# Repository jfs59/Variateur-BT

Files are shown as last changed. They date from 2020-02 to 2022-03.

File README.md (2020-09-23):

# Variateur-BT

  <p align="center">
Addon variateur BT pour Radio Commande.
  
Réalisation d’un variateur double pour bateau et d’un ensemble de 8 voies supplémentaires.
</p> 

<p align="center">
  

</p> 
  </br> </br>
  <p align="center">
  Schéma de principe
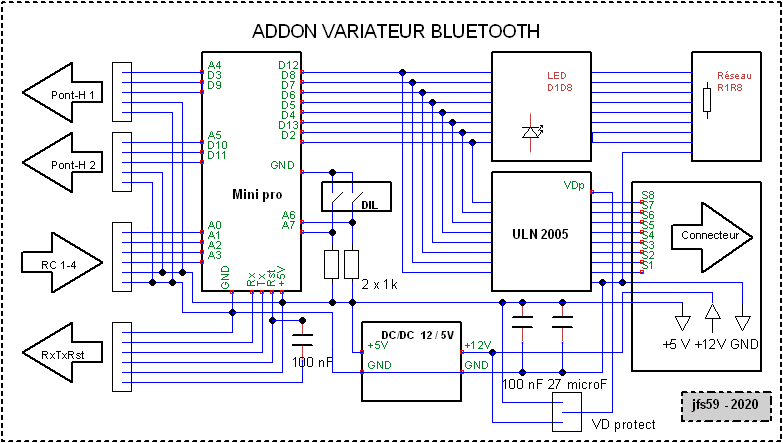
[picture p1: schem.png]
  
</p>

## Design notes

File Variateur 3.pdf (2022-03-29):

### DOUBLE VARIATEUR DE VITESSE POUR BATEAUX

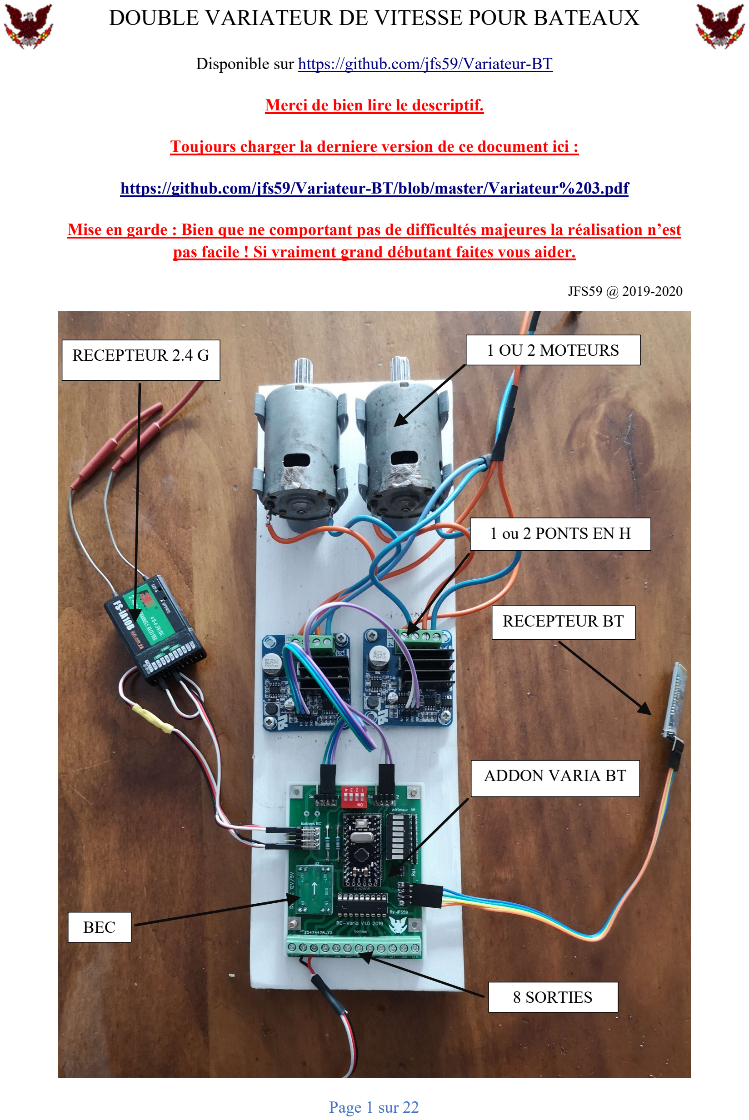
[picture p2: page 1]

Page 1 sur 22

Disponible sur https://github.com/jfs59/Variateur-BT

Merci de bien lire le descriptif.

Toujours charger la derniere version de ce document ici :

https://github.com/jfs59/Variateur-BT/blob/master/Variateur%203.pdf

Mise en garde : Bien que ne comportant pas de difficultés majeures la réalisation n’est pas facile ! Si vraiment grand débutant faites vous aider.

JFS59 @ 2019-2020

### 1 ou 2 PONTS EN H

RECEPTEUR BT

ADDON VARIA BT

RECEPTEUR 2.4 G

BEC

### 8 SORTIES

### 1 OU 2 MOTEURS

Page 2 sur 22

### Table des matières

Page 3 sur 22

Réalisation d’un variateur double et d’un ensemble de 8 voies supplémentaires.

Préambule :

Librement inspiré de : http://bateaux.trucs.free.fr/huit_sorties_auto_v3.html je n’ai gardé pratiquement que l’idée, l’ensemble du code, les schémas ont étés réécris et optimisés tant au niveau du décodage de la mémorisation et des options en fait il reste très peu sinon rien du travail de M Claverie à part l’idée (Il suffit de regarder les extraits de code pour s’en convaincre) qu’il en soit remercié. Certains commentaires sont en Anglais ! Je le déplore mais c’est malheureusement plus concis et souvent plus simple que le Français. La première version était une simple extension sans variateur mais la demande pressante des membres du club on fait que… Cette version bien que non décrite existe toujours et elle est finalisée. (Sauf pour la partie mp3)

Matériel :

Arduino pro mini, afficheur barre de led, réseau de résistance, ULN 2005, Bornes de sorties pour circuit imprimé, convertisseur DC/DC 12V → 5V, IBT-4 (pont en H), Bluetooth JDY-30, Mp3 à définir.

Principe :

L’Arduino décode les signaux RC PPM (4 canaux) et génère les pwm nécessaires à la commande de deux IBT-4 (pont en H) à partir des canaux 1 et 2.

Si fonctionnement sur un seul canal des deux moteurs :

Le canal 2 est affecté au gouvernail et permet suivant le mode de fonctionnement de fonctionner en moteur différentiel.

Le canal 3 est décodé pour activer le canal 4 en sortie ou en demande de bruiteur (module mp3 facultatif)

Le canal 4 est décodé pour commander 8 sorties ULN 2005 selon le principe d’extension de voie. (8 voies sur un canal). En fonction du canal 3 il permet de commander 8 bruits différents, (corne, cloche, diesel)

L’ensemble est configurable par liaison Bluetooth à l’aide d’un programme spécifique développé pour Android. Un mode simulateur est disponible.

Sont configurables : (En plus du mode de fonctionnement)

Limite haute télécommande Canal 1 : 2000 par défaut.

Limite basse télécommande Canal 1 : 1000 par défaut.

Neutre Canal 1 : 1500 par défaut.

Limite haute télécommande Canal 2 : 2000 par défaut.

Limite basse télécommande Canal 1 : 1000 par défaut.

Neutre Canal 2 : 1500 par défaut.

Largeur zone neutre : +/- 50 par défaut.

Pourcentage AV Pourcentage AR Canal 1 : 100% par défaut.

Pourcentage AV Pourcentage AR Canal 2 : 100% par défaut.

Mode de fonctionnement des 8 sorties : Monostables Bistables : 4 monostables, 4 bistables par défaut.

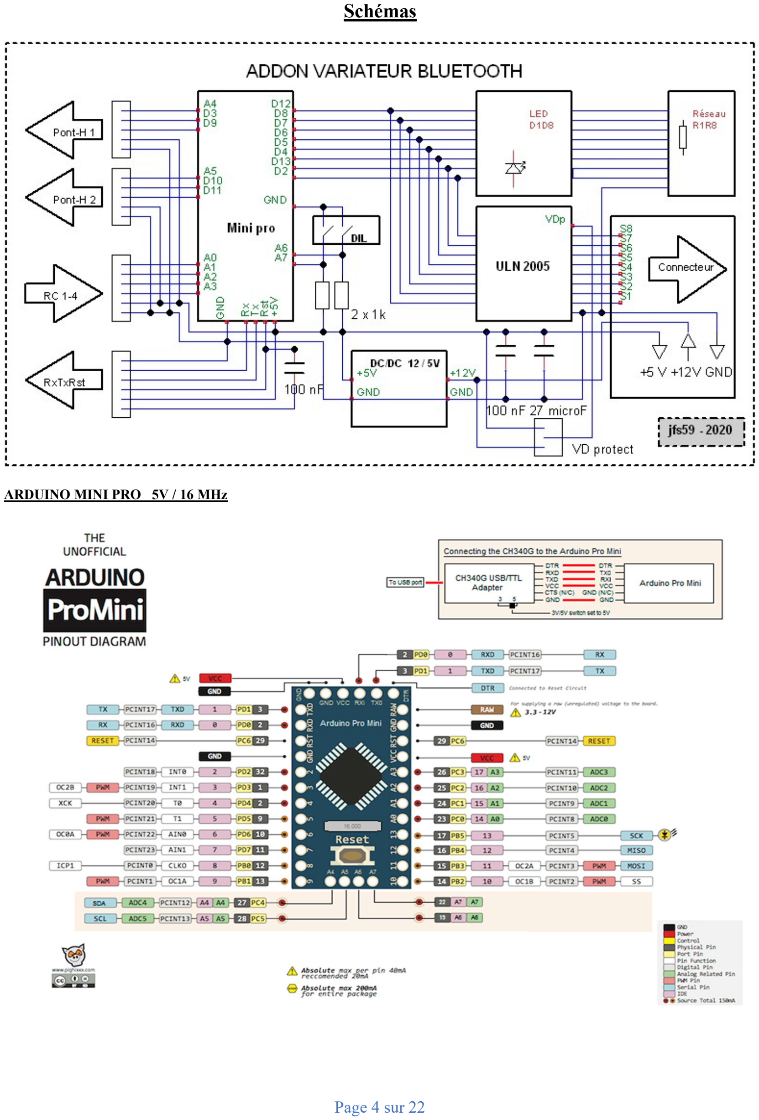
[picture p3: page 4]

Page 4 sur 22

Schémas

ARDUINO MINI PRO 5V / 16 MHz

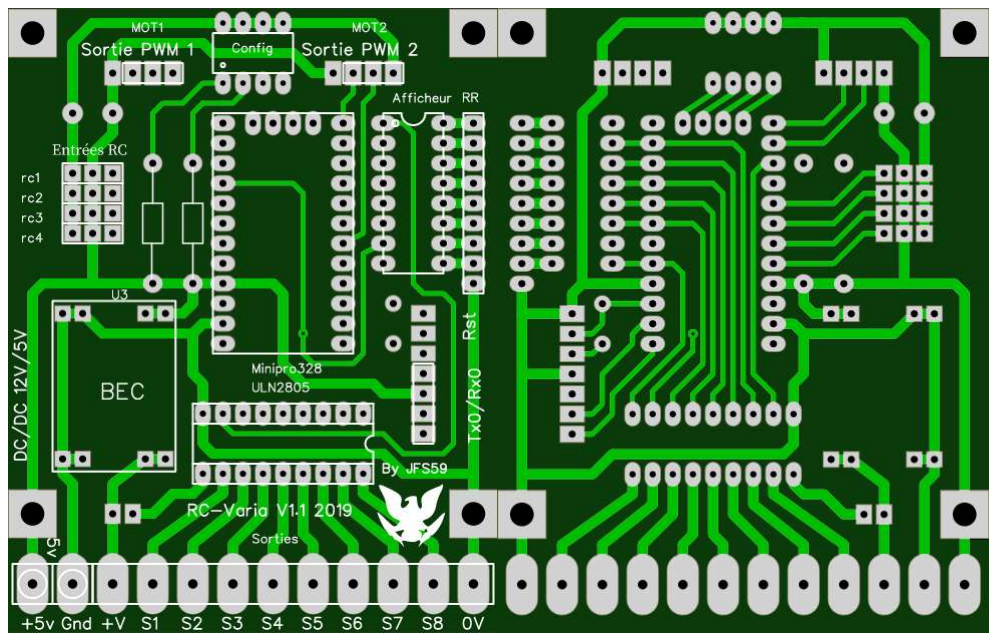
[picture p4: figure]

Page 5 sur 22

Circuit imprimé

Circuit double face, trous métallisés, vernis épargne, et sérigraphie. Dessiné et routé par mes soins. Réalisé par une entreprise.(Le résultat donne un CI professionnel) Le routage et le design sont donnés ci-dessous mais les fichiers Gerber sont et resteront ma propriété. Le circuit imprimé V3 est disponible pour la somme de 5 € couvrant les frais de réalisation et transport. ( Me contacter au club de Raismes. )

Remarque : l’utilisation de A6 et A7 en numérique implique des résistances de tirage au +. A6 et A7 étant purement analogique il faut utiliser une astuce de programmation.

Le bootloader de la carte devra être changé pour empêcher le clignotement au reset de la carte ! sinon il faut faire attention au rôle de la sortie S7 qui va s’allumer au reset !!

Dans la version 3 le circuit imprimé a changé car la programmation Bluetooth a pris le dessus sur la configuration par DIL (cf. schéma de principe) des sorties supplémentaires pour les ponts en H sont disponibles. Elles permettront d’utiliser des ponts en H autre que l’IBT4.

L’entrée commune de protection par diodes de l’ULN peut être reliée soit au 12 V soit au 5 V (version 3) soit rester non utilisée (cas de tensions différentes sur les sorties)

### Bien vérifier à la commande car de nombreuses variantes incompatibles !!

ATTENTION : il faut un Pro Mini Atmega328P 5V/16M avec le même brochage du CI de [ A4 à A7 ]

Attention il existe des modules avec une broche Gnd en plus ils ne sont pas directement compatibles.

Pour ces modèles il est toujours possible d’adapter en passant des fils sous la carte.

Attention : Les Atmega168 ne sont pas compatibles ! Méfiez vous des revendeurs qui disent le contraire.

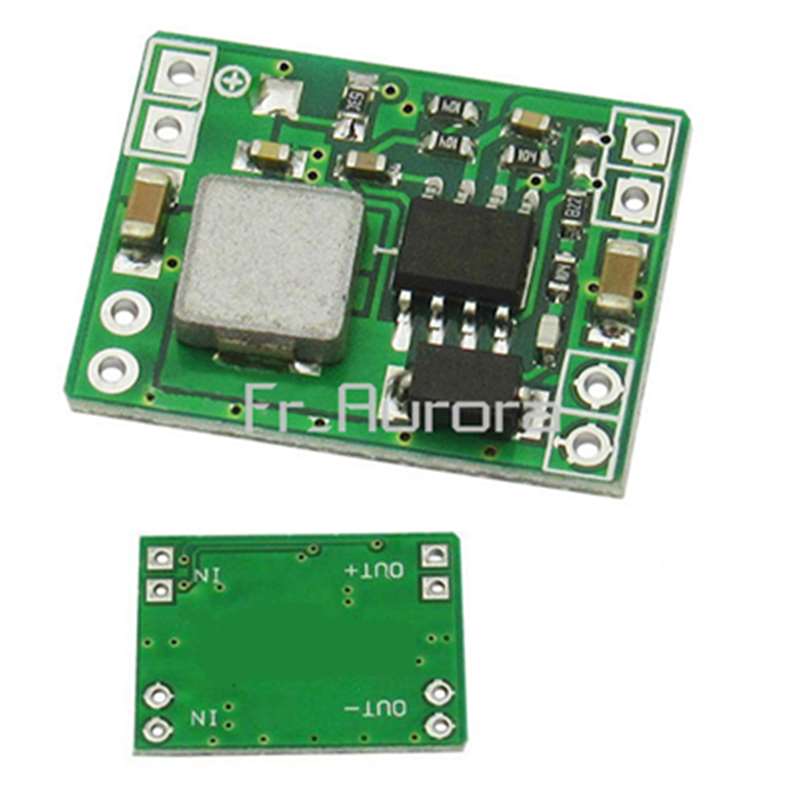
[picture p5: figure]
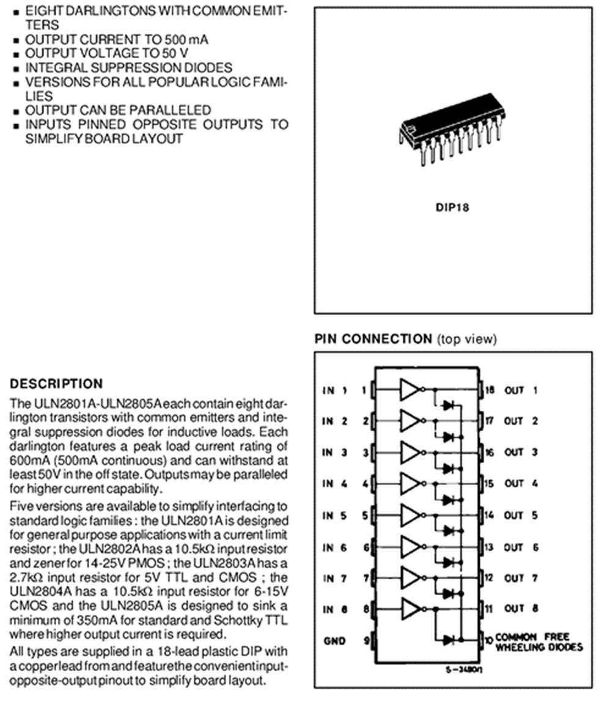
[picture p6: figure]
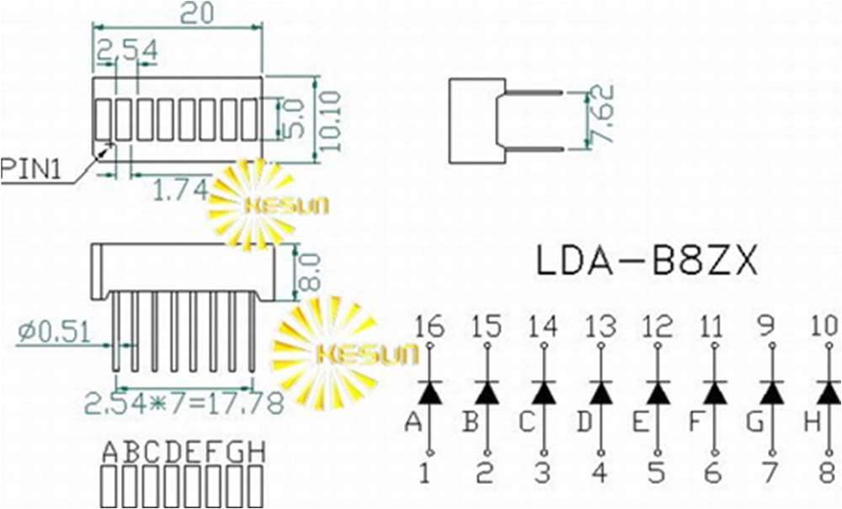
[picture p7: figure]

Page 6 sur 22

Composants et sous-ensembles.

Convertisseur DC/DC 12 V/ 5 V

Utilisé pour alimenter l’Arduino et les diodes de visualisation. Une sortie 5 V est prévue pour alimenter un montage externe.

Sur la première version montage du convertisseur composant en dessous !

Version 3 le convertisseur est positionné composants au-dessus.

ULN 2005 interface de puissance

Permet de relayer les sorties Arduino afin de disposer d’un courant de sortie plus important et d’une tension différente, peuvent se mettre en // pour augmenter le courant de sortie il suffit de les souder patte pour patte l’un au-dessus de l’autre,

Diode anti retour de protection communes à toutes les sorties. (Attention si vous n’êtes pas sûr de l’utilisation faites-vous aider)

Les sorties OUT sont mises à la masse quand un niveau haut (1) est présent à l’entrée correspondante.

Bargraphe led

Visualise l’état des canaux et donc des sorties de puissance. Les cathodes sont reliées à la masse à travers un réseau des 8 résistances dont le point commun est à la masse.

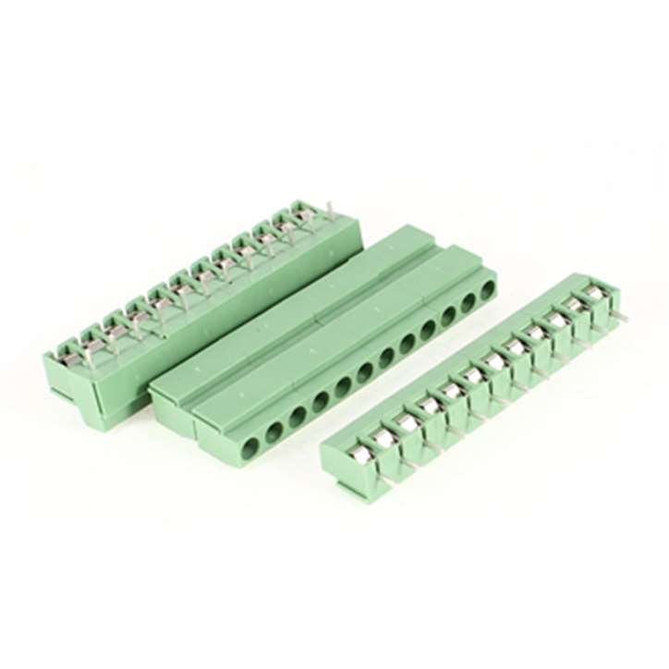
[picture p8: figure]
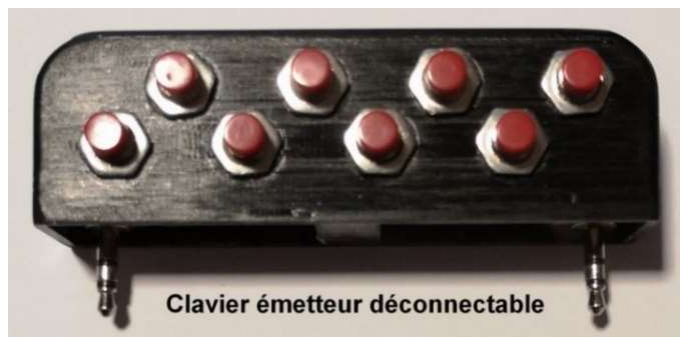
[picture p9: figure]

Page 7 sur 22

Interrupteur DIL

Permettent de choisir le mode de fonctionnement de 0 à 15. Depuis la version Bluetooth le mode est configurable par le programme Android.

Le DIP ne fait plus que 2 rangées sur la version 3.

Off Off : mode Bluetooth. On Off : 1 moteur.

Off On : 2 moteurs 1 commande. On On : 2 moteurs 2 commandes.

Réseau de 8 résistances

Choisir la valeur entre 470 Ohm et 1 K Ohm,

Borniers a vis clipsables,

Par 2 ou 3 il en faut 12 : 2 X6 ou 3 X4

Un fichier imprimante 3D est disponible sur le

Github

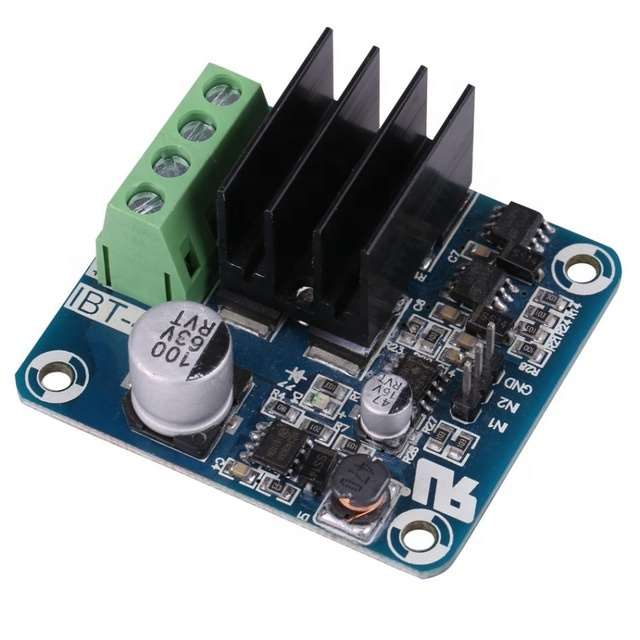
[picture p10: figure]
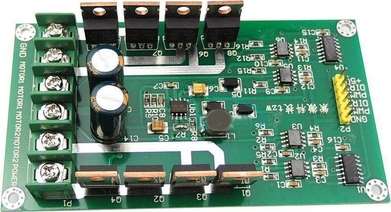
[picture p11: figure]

Page 8 sur 22

IBT4 Pont en H

Caractéristiques :
- Module driver Pont H à courant élevé (50A) MOSFET
- Isolation galvanique du signal PWM.
- Rotation avant et arrière du moteur, deux entrées PWM au maximum 200kHz
- Alimentation 3.3V à 15V.

Le module possède sa propre alimentation donc seulement 3 fils à brancher la masse et les deux entrées PWM.

Double Pont en H

Caractéristiques :
- Module driver Pont H (10 A ou 15 A) MOSFET

Courant nominal : 10A

Courant de crête : 30A

Moteur avant : DIR = 1 PWM = PWM

Inversion du moteur : DIR = 0 PWM = PWM

Frein de stationnement : DIR = X PWM = 0 (X est un état arbitraire)

(Pas compatible encore en développement)

Monster Pont en H

Caractéristiques :
- Module driver Pont H à courant élevé (30A) MOSFET

(Pas compatible encore en développement)

Page 9 sur 22

IBT2 Pont en H

Caractéristiques :
- Module driver Pont H à courant élevé (43A) MOSFET

(Pas compatible encore en développement)

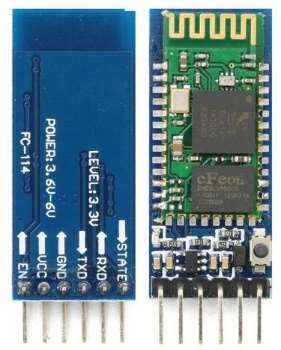
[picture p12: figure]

Module Bluetooth HC 05 / JDY-30

Il permet la configuration du variateur (mode de fonctionnement) et des differentes sorties (monostable, bistable) il permet aussi un mode simulation des sorties et des voies du variateur. (Pas utile lors du fonctionnement normal)

Module FTDI / USB

Il permet la programmation du variateur (Pas utile lors du fonctionnement si vous n’avez pas besoin de changer de fichier hex)

Page 10 sur 22

Chronologie de câblage :

Câblage de la version Bluetooth.

Souder les deux résistances cms 1K et vérifier en testant sur le circuit. (Consulter un tuto de soudage cms) Souder la platine alimentation BEC.
Souder une ligne de bornier (possibilité de souder : +V, gnd, +5v uniquement)
Brancher une tension >6 V sur Gnd, +V et vérifier la présence du + 5 V.
Souder le connecteur Rx/Tx Bluetooth et le condensateur c3 de 100 nf. (Pour permettre le flash de la carte Arduino il est aussi possible de flasher à la volée par le connecteur « ftdi »)
Souder les pattes extrêmes du réseau et vérifier le sens et les valeurs. (Souder le reste des pattes)
Souder le support d’afficheur. Placer l’afficheur et vérifier chaque segment en injectant +5 v sur les pastilles correspondantes au niveau de la carte Arduino.
Souder la plaque Arduino MiniPro. (Eventuellement le bootloader noled aura été chargé mais il peut l’être après) Il est peut-être possible d’utiliser une carte non standard (avec gnd) en tordant les pattes A4 A5 A6 A7 (sans garantie)
Charger un sketch (programme) dans l’Arduino.
Mettre sous tension entre Gnd et +V (tension > 6V). Le programme démarre est on doit observer à chaque reset un défilement « bargraphe » sur l’afficheur.
Souder le support ULN.
Placer un ULN et vérifier le bon fonctionnement de chaque sortie (S1 a S8). (Terminer les soudures borniers si nécessaire) Souder l’interrupteur DIL éventuellement sur support.
Souder les connecteurs de sortie PWM. Souder les différents connecteurs. Les condensateurs de découplage sont facultatifs. (Procédure incomplète)

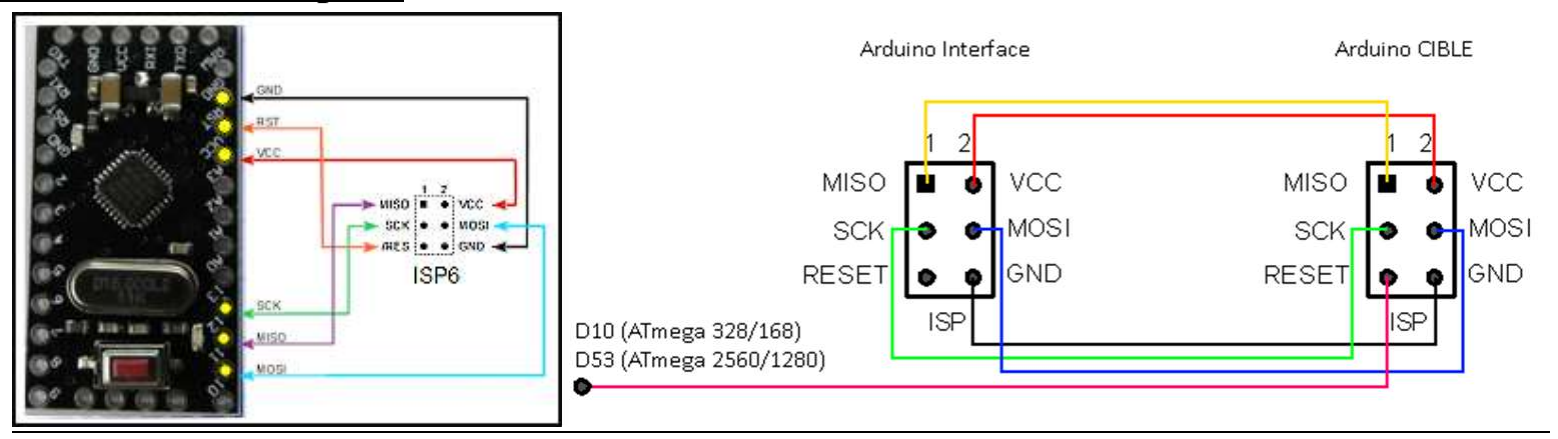
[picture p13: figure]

Page 11 sur 22

Compilation et Flash du Bootloader

Repérage des connecteurs de la mini pro :

Sur le circuit imprimé vous pouvez utiliser les broches support de l’afficheur.
Se référer à la procédure de flash soit avec un ISP soit avec un Arduino câblé en ISP et le programme (Arduino as ISP). Le bootloader zéros LED est disponible sur le GitHub.
Il faut évidemment placer le bootloader noled dans le dossier Arduino et éditer le Board.txt ! https://github.com/jfs59/Variateur-BT/blob/master/mod.ATmegaBOOT_168_atmega328.hex
Ce bootloader no LED a été compile par mes soins et fonctionne avec la mini pro sans problème. Il permet de supprimer le clignotement lors du boot du variateur. (Il n’est pas indispensable si l’activation de la sortie au démarrage ne pose pas de problème sur la maquette)
Compiler un bootloader : (Pour rappel ou besoin différent)

charger et installer GnuWin32

copier : ATmegaBOOT_168.c et Makefile
dans le dossier bin de gnuwin32
(pour aller dans le dossier en ligne de commande : cd \"program files (x86)\GnuWin32\bin" )

dans le makefile : modifier (modification du nombre de clignotement au boot)

atmega328: CFLAGS += '-DMAX_TIME_COUNT=F_CPU>>4' '-DNUM_LED_FLASHES=1' -DBAUD_RATE=57600

en mettant zéro à la place du 1

atmega328: CFLAGS += '-DMAX_TIME_COUNT=F_CPU>>4' '-DNUM_LED_FLASHES=0' -DBAUD_RATE=57600

Lancer un : ./make atmega328 (ne pas oublier ./)

PS C:\program files (x86)\GnuWin32\bin> ./make atmega328
avr-gcc -g -Wall -Os -mmcu=atmega328p -DF_CPU=16000000L '-DMAX_TIME_COUNT=F_CPU>>4' '-DNUM_LED_FLASHES=0' -DBAUD_RATE=57600 -c -o ATmegaBOOT_168.o ATmegaBOOT_168.c
avr-gcc -g -Wall -Os -mmcu=atmega328p -DF_CPU=16000000L '-DMAX_TIME_COUNT=F_CPU>>4' '-DNUM_LED_FLASHES=0' -DBAUD_RATE=57600 -Wl,--section-start=.text=0x7800 -o ATmegaBOOT_168_atmega328.elf ATmegaBOOT_168.o
avr-objcopy -j .text -j .data -O ihex ATmegaBOOT_168_atmega328.elf ATmegaBOOT_168_atmega328.hex
rm ATmegaBOOT_168_atmega328.elf ATmegaBOOT_168.o
PS C:\program files (x86)\GnuWin32\bin>

Renommer le fichier obtenu en mod.ATmegaBOOT_168_atmega328.hex
puis le transférer dans le dossier C:\Program Files (x86)\Arduino\hardware\arduino\avr\bootloaders\atmega

Editer le boards.txt et changer :
pro.menu.cpu.16MHzatmega328.bootloader.file=atmega/mod.ATmegaBOOT_168_atmega328.hex
dans la section pro mini
enfin lancer l'ide arduino, et avec un nano et le programme arduinoisp faire un flash arduino as isp du bootloader lancer 2 fois si le premier ne passe pas ! Puis recharger le sketch.

Page 12 sur 22

Pour flasher le .hex vous pouvez utiliser Xloader en USB ou une autre méthode que vous connaissez. Xloader

A rechercher sur internet ou directement sur le GitHub https://github.com/jfs59/Variateur-BT/blob/master/Outils/XLoader.zip
Choisir le port com (pas forcément le 4) et le fichier Variateur.ino.eightanaloginputs.hex choisir Duemilanove/Nano(ATmega328) appuyer sur upload. La procédure fonctionne je l’ai essayée. (Il est impossible de flasher le bootloader par cette méthode)

Gestion des paramètres en Bluetooth sur ANDROID
Varia config 1.0:
Varia Config 1.0 (et les futures évolutions) permet de gérer les paramètres du variateur a l’aide d’un téléphone ou d’une tablette ANDROID. (Il n’y aura pas d’autres développement que sur ANDROID)
Développé par mes soins à partir de http://ai2.appinventor.mit.edu/
Le programme a beaucoup évolué (et évoluera encore) en fonctions des options ajoutées et des besoins.
Il est disponible ici : https://github.com/jfs59/Variateur-BT/blob/master/Variateur.apk

Ce n’est pas la dernière version et elle n’assure donc pas tout le fonctionnement et toutes les simulations.
Le programme sera mis à jour en fonctions des versions stables qui seront développées ainsi que le sketch Arduino. Il est préférable qu’ils soient de la même période l’un n’allant pas sans l’autre.
Sont en développement :
- Gestion des sons mp3.
- Support des différents ponts en H.
- Vitesses différentielles des moteurs en fonction du gouvernail.
- Résolution de bug de communication Bluetooth.

Commande Bluetooth actuelles :
const char CmdCfg_Str[] PROGMEM = "CmdCfg"; const char CmdEnr_Str[] PROGMEM = "CmdEnr"; const char CmdSim_Str[] PROGMEM = "CmdSim"; const char DemCfg_Str[] PROGMEM = "DemCfg";
const char DemVer_Str[] PROGMEM = "DemVer";
const char DemCon_Str[] PROGMEM = "DemCon";

Ces commandes peuvent être utilisée sur le moniteur série sans module Bluetooth.

<DemCfg> demande de config le variateur envoie sur la ligne série la config en cours.
<DemVer> demande de version le variateur envoie sur la ligne série le numéro de version du programme.
<DemCon> demande de connexion du module bluetooth.

CmdCfg suivie de la config <CmdCfg|1|11|1500|1000|2000|1500|1000|2000|50|100|100|100|100|0|0|0|0|0|0|0|0|1500|1500|1500|1500|1500|1500|1500|1500> Donne une nouvelle configuration au variateur.
<CmdEnr> demande d’enregistrement. La config courante est enregistrée en EEPROM et le variateur reboot.

CmdSim suivie des valeurs de simulation. Autorise ou interdit la simulation est programme les valeurs de simulation de la ligne courante. (A compléter)

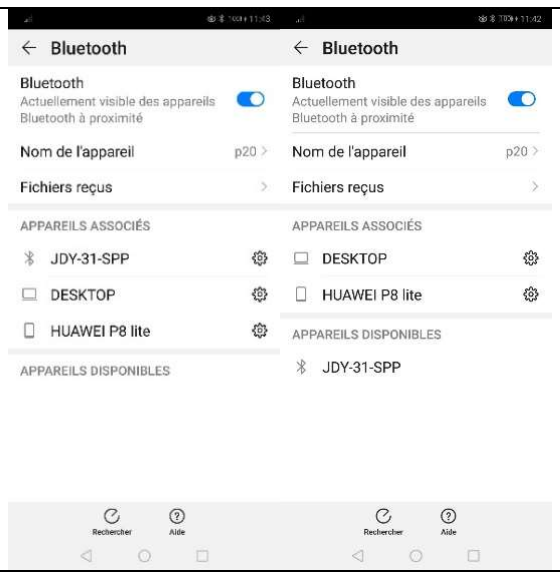
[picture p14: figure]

Page 13 sur 22

Association Bluetooth : Recherche.

Aller dans paramètres Bluetooth rechercher les appareils disponibles et cliquer sur le JDY-31 une fenêtre d’association va apparaitre.

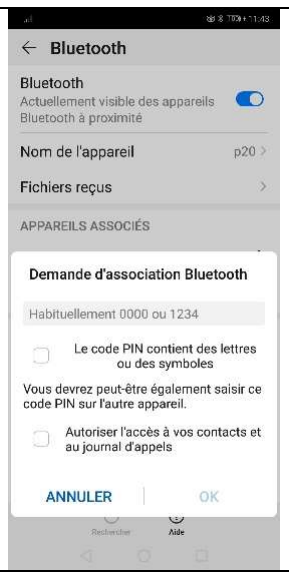
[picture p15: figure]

Association Bluetooth : Code.

Le périphérique Bluetooth demande une confirmation pour s’associer. Le code est 1234. Ne pas cocher les cases supplémentaires.

Association Bluetooth : Association

Une fois associé le périphérique reste dans la liste jusqu’à suppression. Il ne faut donc l’associer normalement qu’une seule fois.

Programme Variateur : Ecran de démarrage

Lancer le programme variateur un splash screen apparait le temps du démarrage.

Page de connexion :

La page connexion apparait. Il faut se connecter avant de continuer sinon vous avez un message disant que le Bluetooth n’est pas connecté.

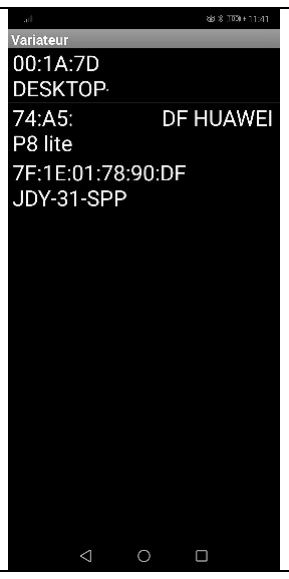
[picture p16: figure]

Choix du périphérique Bluetooth :

Normalement le JDY 31 est dans la liste le choisir. Le téléphone va essayer de se connecter (Cela peut prendre un certain temps)

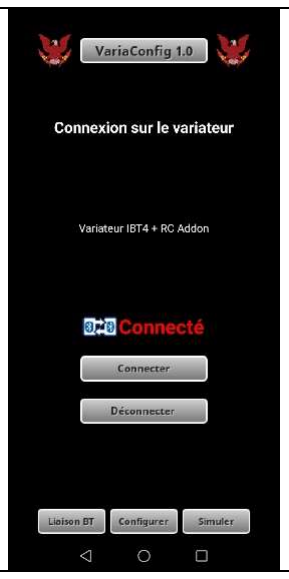
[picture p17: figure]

Connexion :

La page de connexion apparait et un message de version est affiché. Les autres pages sont maintenant disponibles.

Page de mode.

Affiche le mode de fonctionnement du variateur ainsi que le hardware à utiliser.
Permet d’activer le mode mp3.

Page 14 sur 22

Choix du mode :

Permet de choisir un mode de fonctionnement dans les modes disponibles.

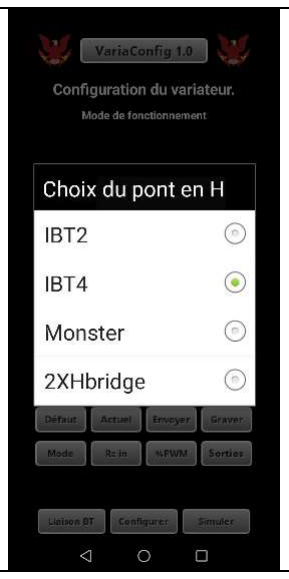
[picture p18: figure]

Choix du matériel :

Permet de choisir le pont en H utilisé par le variateur.
(Seul IBT4 fonctionne pour l’instant)

Paramètres RC :

Permet de choisir les limites du signal RC pour adapter les valeurs.

Paramètres variateur :

Permet de choisir les limites de la tension de sortie en % de batterie d’alimentation du pont en H.

Paramètres Sorties :

Permet de choisir l’action sur les sorties (monostable, bistable) les seuils sont pour l’instant non modifiables.

Valeurs par défaut :

Permet de recharger les valeurs par défaut du variateur dans le programme.

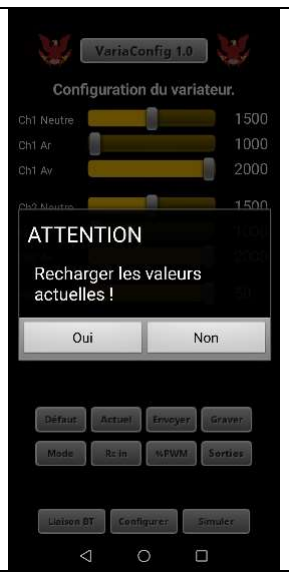
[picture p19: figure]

Valeurs actuelles :

Permet de recharger les valeurs présentent dans le variateur.

Envoyer la configuration :

Permet de charger les valeurs du programme dans le variateur. Elles sont effectives de suite mais ne sont pas sauvegardées. Retour au valeurs sauvegardées au redémarrage.

Page 15 sur 22

Enregistrer la configuration :

Permet de graver les valeurs du programme dans le variateur (EEPROM). Elles deviennent les valeurs de démarrage. Le variateur redémarre automatiquement suite à la sauvegarde.

Simulateur :

Permet de modifier les valeurs en sortie des ponts en H. Et de modifier les valeurs des sorties. Le mode simulateur surpasse les valeurs de la radiocommande.

Page About :

Elle contient les infos sur le programme.

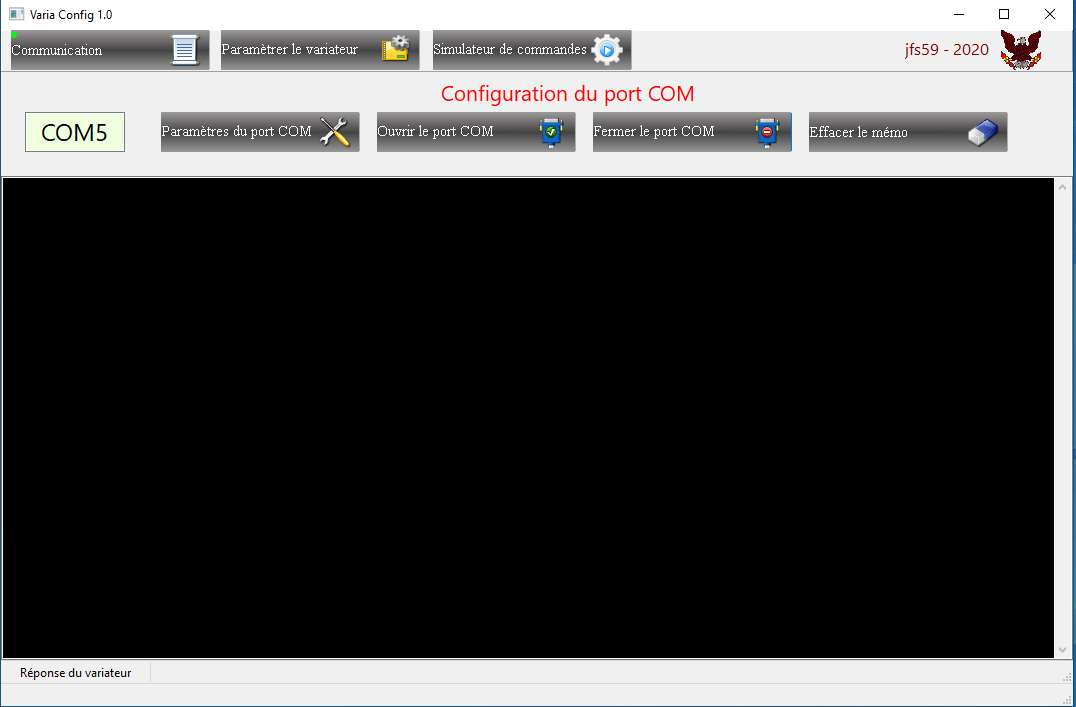
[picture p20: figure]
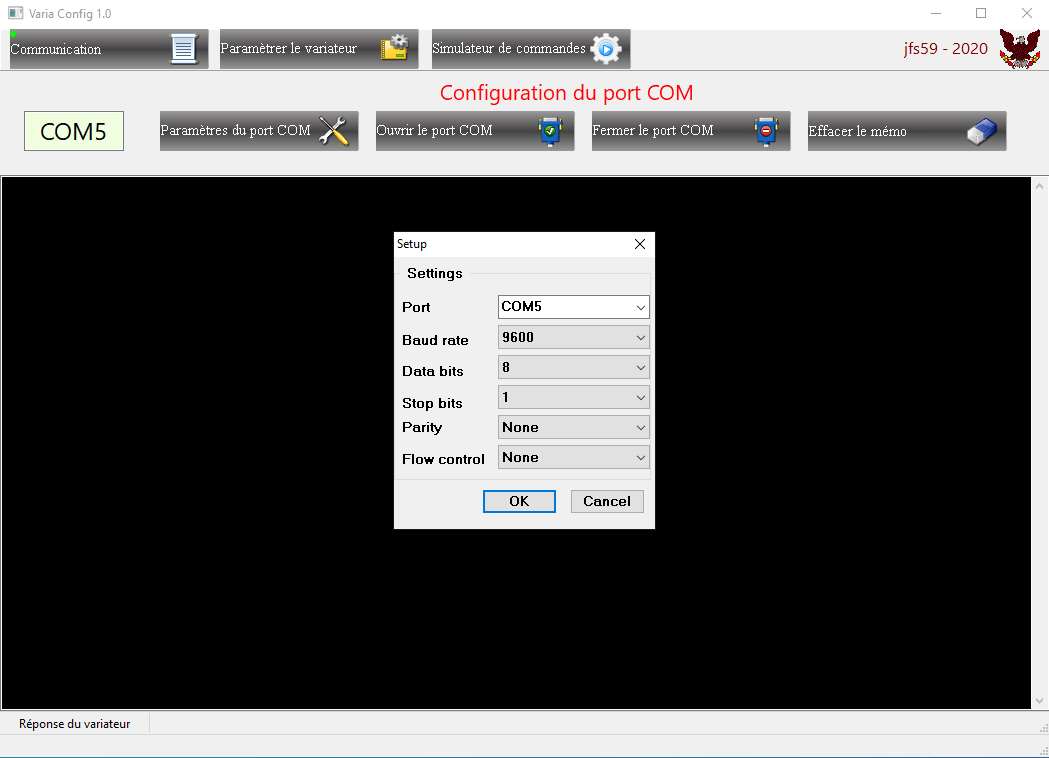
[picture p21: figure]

Page 16 sur 22

Gestion des paramètres sur PC Windows

Le programme de gestion a été écris en Lazarus (Pascal). Il permet de modifier tous les paramètres du variateur ainsi que la simulation.

Page communication :

Choisir le port COM sur lequel est branché le variateur. La configuration par défaut doit être bonne et donc ne pas la modifier.

Ouvrir le port. Une demande est envoyée au variateur qui reboot et réponds par le numéro de version et la configuration actuelle.

La configuration est décodée et les valeurs sont affichées dans le programme.

Un bouton permet de fermer le port et un autre d’effacer le tableau de dialogue.

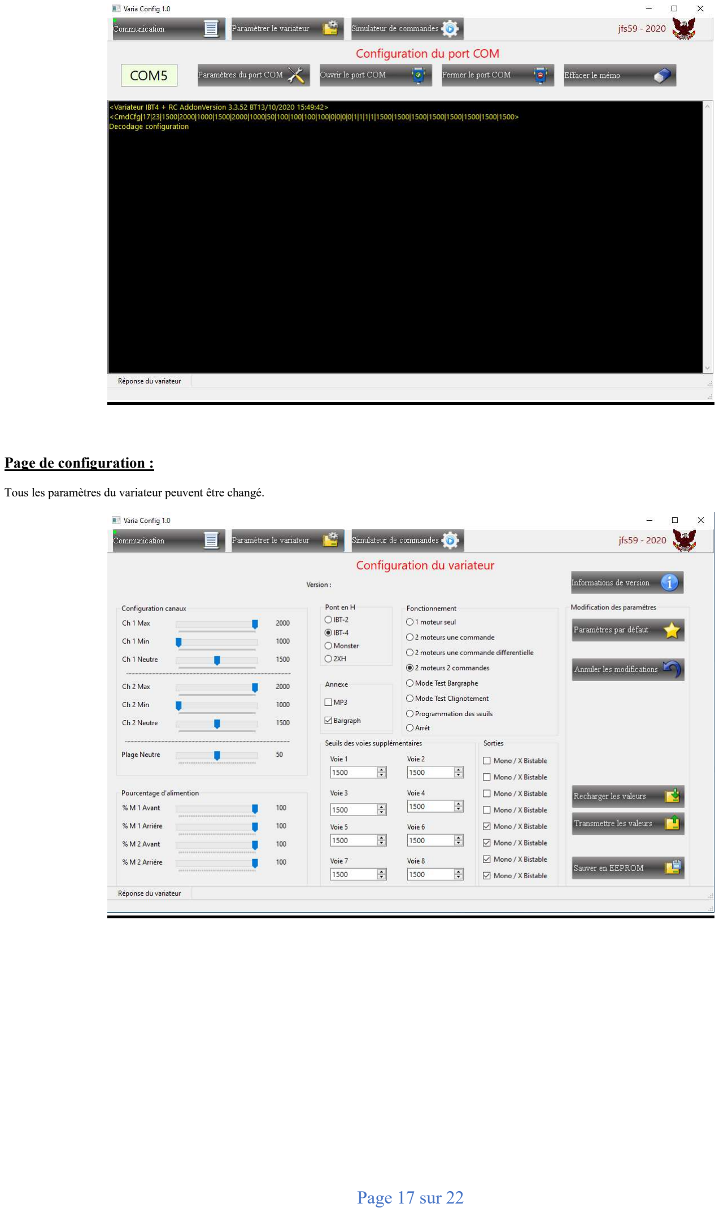
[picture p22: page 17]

Page 17 sur 22

Page de configuration :

Tous les paramètres du variateur peuvent être changé.

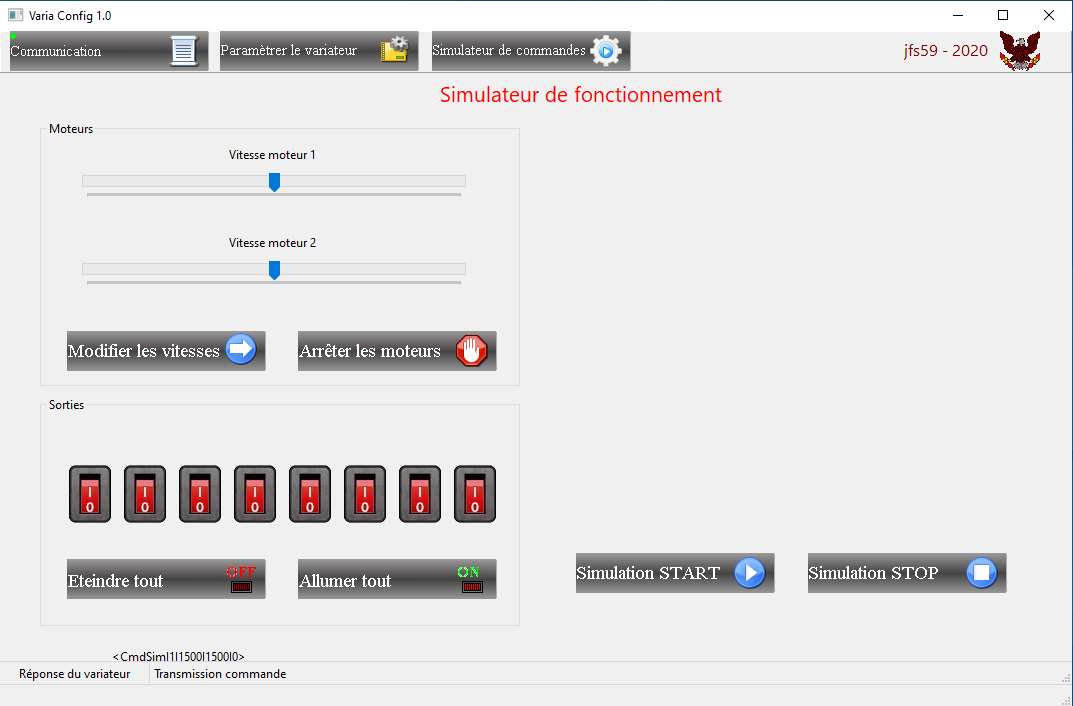
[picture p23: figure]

Page 18 sur 22

Page de simulation :

Page 19 sur 22

Structure et extraits du programme Arduino

Le code complet ne sera pas publié par contre je laisse libre accès au fichier compilé et donc au fichier hexadécimal à programmer avec un USBasp ou un FTDI. (Les initiés comprendront la terminologie) de même je donne libre accès au BOOLOADER modifié. Je peux sous certaines conditions faire pour vous la mise à jour.

Variables de configurations :

struct __attribute__ ((packed)) RC_Config {
byte Structure;
byte ModeFonctionnement;
unsigned int Voie_1_Neutre; unsigned int Voie_1_Arriere; unsigned int Voie_1_Avant; unsigned int Voie_2_Neutre; unsigned int Voie_2_Arriere; unsigned int Voie_2_Avant; byte Plage_Neutre;
byte PourcentAvantV1;
byte PourcentArriereV1;
byte PourcentAvantV2;
byte PourcentArriereV2;
byte ModeSorties[8];
int Seuil_Bouton[8];
unsigned long Flag; // controle d'integrité sauvegarde };

Configuration par défaut :

void DefinirConfigDefaut() { Configuration.Flag = 123456789;
Configuration.STRUCT_VERSION = 1; Configuration.ModeFonctionnement = 23 ; // 2 moteurs 2 commandes séparées. Configuration.Voie_1_Neutre = 1500;
Configuration.Voie_1_Avant = 2000;
Configuration.Voie_1_Arriere = 1000; Configuration.Voie_2_Neutre = 1500; Configuration.Voie_2_Avant = 2000; Configuration.Voie_2_Arriere = 1000; Configuration.Plage_Neutre = 50; Configuration.PourcentAvantV1 = 100; Configuration.PourcentArriereV1 = 100; Configuration.PourcentAvantV2 = 100; Configuration.PourcentArriereV2 = 100;

for ( int n = 0; n < 4; n ++) { Configuration.ModeSorties[n] = 0 ; }

for ( int n = 4; n < 8; n ++) { Configuration.ModeSorties[n] = 1 ;} for ( int n = 0; n < 8; n ++) {Configuration.Seuil_Bouton[n] = 1500 ;} }

Page 20 sur 22

Gestion des entrées RC par interruption :

static byte rcOld; // Prev. states of inputs
volatile unsigned long rcRises[4]; // times of prev. rising edges volatile unsigned long rcTimes[4]; // recent pulse lengths volatile unsigned int rcChange=0; // Change-counter
// Be sure to call setup_rcTiming() from setup()
void setup_rcTiming() {
rcOld = 0;
pinMode(A0, INPUT_PULLUP); // pin 14, A0, PC0, for pin-change interrupt pinMode(A1, INPUT_PULLUP); // pin 15, A1, PC1, for pin-change interrupt pinMode(A2, INPUT_PULLUP);
pinMode(A3, INPUT_PULLUP);
PCMSK1 |= 0x0F; | // Four-bit mask for four channels
PCIFR |= 0x02; | // clear pin-change interrupts if any
PCICR |= 0x02; | // enable pin-change interrupts
}
// Define the service routine for PCI vector 1 ISR(PCINT1_vect) {
byte rcNew = PINC & 15; // masquage 4 bits, A0-A3 byte changes = rcNew^rcOld; // verif changement bit byte channel = 0;
unsigned long now = micros(); // micros() ok
while (changes) {
if ((changes & 1)) { // Did current channel change? if ((rcNew & (1<<channel))) { // Check rising edge rcRises[channel] = now; // Is rising edge
} else { | // Is falling edge
rcTimes[channel] = now-rcRises[channel]; }
}
changes >>= 1; // shift out the done bit ++channel;
++rcChange;
}
rcOld = rcNew; // Save new state }

Message de Boot et trame de configuration Bluetooth : (liaison série 9600 bauds)

<Variateur IBT4 + RC Addon
Version 3.3.26 BT
24/09/2020 11:29:43
>
<CmdCfg|1|23|1500|1000|2000|1500|1000|2000|50|100|100|100|100|0|0|0|0|0|0|0|0|1500|1500|1500|1500|1500|1500|1500|1500> Mode de fonctionnement : 23

Page 21 sur 22

Interconnexions :

Gnd

IN1

IBT-4

IN2

P+
P-M1
M2

BAT

Gnd

IN1

IBT-4

IN2

P+
P-M1
M2

BAT

BAT +

+

+

SORTIE 5V
FIXE

Exemple de câblage d’une LED avec résistance de limitation
Soit sur alimentation accessoire soit en sortie 5V. Mixage possible. Attention ne pas utiliser les diodes de protections communes dans ce cas.

Récepteur RC

Les entrées RC alimentent le récepteur en 5 V attention de ne pas alimenter le récepteur par une autre alimentation en même temps !

### 1 ou 2 moteurs les batteries peuvent être commune avec la

batterie des accessoires faire les liaisons + et masse.

Exemple de câblage IBT- 4

Ne pas oublier la protection en cas de charges inductives

Module
Bluetooth

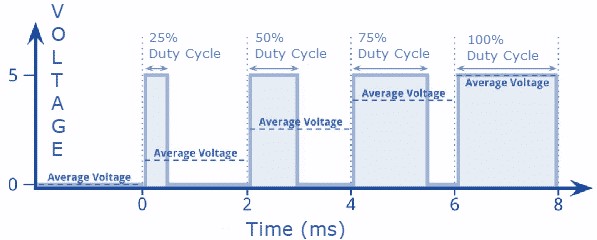
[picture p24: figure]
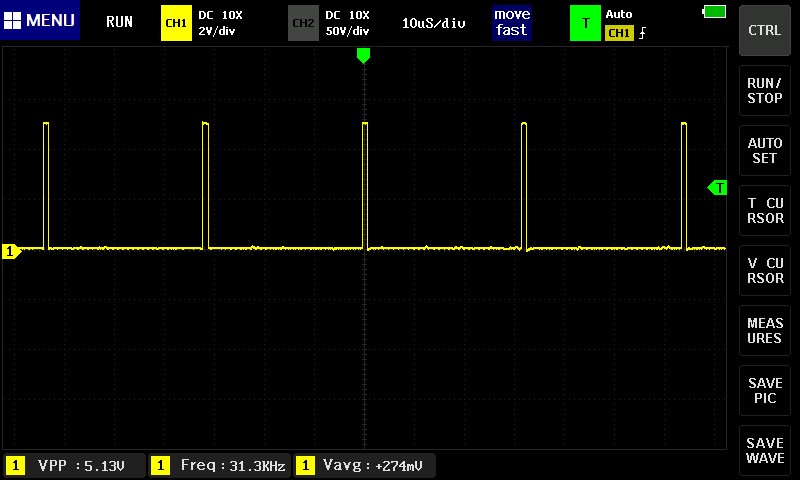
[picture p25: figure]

Page 22 sur 22

Chronogrammes :

Explication du PWM : Le signal peut varier de 0 à 100% en changeant le temps du signal à l’état haut. Cela correspond donc à alimenter avec une tension correspondant à la moyenne du temps à l’état haut par rapport à l’état bas (Duty cycle).

Le pont en H sera alimenté par une tension PWM déterminée par le processeur en fonction du signal RC.

Tension minimum le moteur tourne à peine.

Tension à 50% le moteur tourne à mi-vitesse.

Tension à 100% le moteur tourne à pleine vitesse.

La fréquence du PWM a été fixée à un peu plus de 30 kHz : La fréquence de base du AT328 la est de 31250 Hz.

Les chronogrammes sont ceux observés sur une des sorties (10) du micro pro en injectant sur l’entrée RC la sortie voie 1 du récepteur.

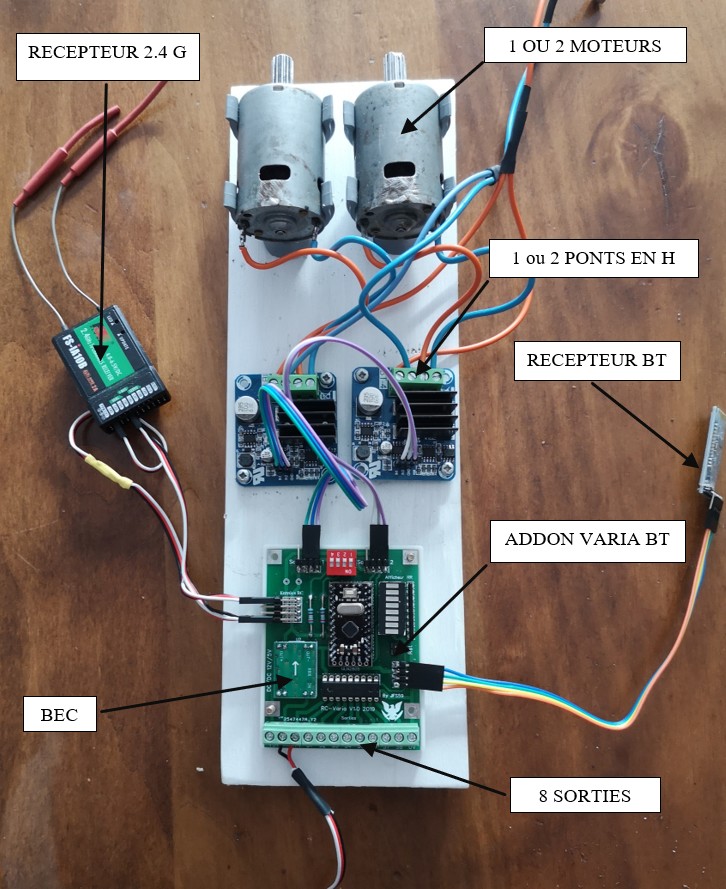
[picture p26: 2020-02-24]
presentation.jpg

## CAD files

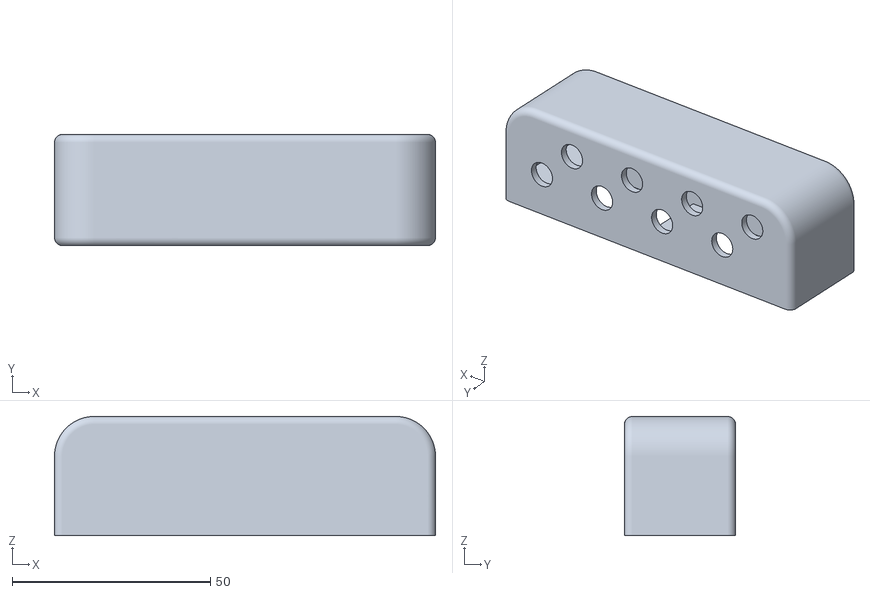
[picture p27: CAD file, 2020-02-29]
addon flysky.STL
96.0 x 28.0 x 30.0

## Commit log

2020-02-24 Create Liste des fichiers
2020-02-29 Update Liste des fichiers
